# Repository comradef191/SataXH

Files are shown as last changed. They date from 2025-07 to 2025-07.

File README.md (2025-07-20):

# SataXH
This is a simple breakout board that allows you to break-out the 12v & 5v rails of a SATA power connector to JSTXH connectors, allowing for easy integration of non-standard components into a PC such as an ESP-based RGB controller, which requires a 5v source but lacks a PC-compatible power input.

# NOTICE
As of 20JUl25 this board has not yet been tested, however should function.
If you wish to export your own Gerber files, please make sure to have [the Nasin Nanpa font](https://github.com/ETBCOR/nasin-nanpa) installed

## Vendors
- None... yet!

Contact me on Discord if you want to add yourself to this list!

## Bill of Materials
This BoM lists exclusively through-hole components, as SMD components will be assembled for you by JLCPCB/ect

|  Component |QTY | Cost  |  Comment |  Sourcing URL |
|---|----|---|---|---|
|JST-XH 2-Pin | 8  | $0.80 | Power Output | https://www.digikey.co.uk/en/products/detail/jst-sales-america-inc/B2B-XH-A/1651045 |
|1x2 5.08 Screw Terminal | 2  | $2.66 | Power Output | https://www.digikey.co.uk/en/products/detail/phoenix-contact/1729128/260615 |
|SATA 7+15 PCB Connector | 1  | $4.09 | Power Input | https://www.digikey.co.uk/en/products/detail/amphenol-icc-fci/10101788-002CLF/5207025 |

## Gallery



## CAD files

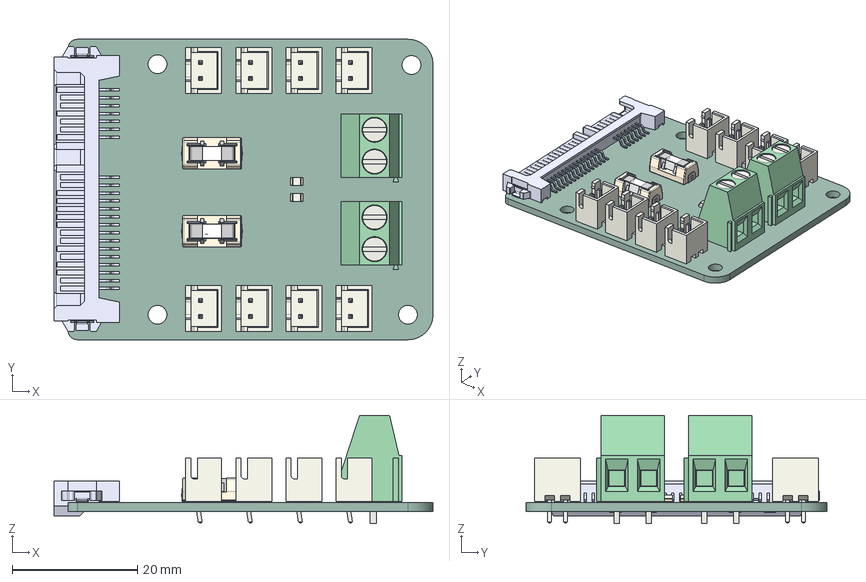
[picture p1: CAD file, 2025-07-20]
SataXH.step
60.5 x 48.0 x 17.3 mm
¼þ1 x 2
¼þ2 x 4
µ艝 x 2
LED_0805_2012Metric x 2
TerminalBlock_Phoenix_MKDS-1,5-2-5.08_1x02_P5.08mm_Horizontal x 2
10101788-002CLF--3DModel-STEP-533217
JST_XH_B2B-XH-A_1x02_P2.50mm_Vertical x 8
SataXH_PCB

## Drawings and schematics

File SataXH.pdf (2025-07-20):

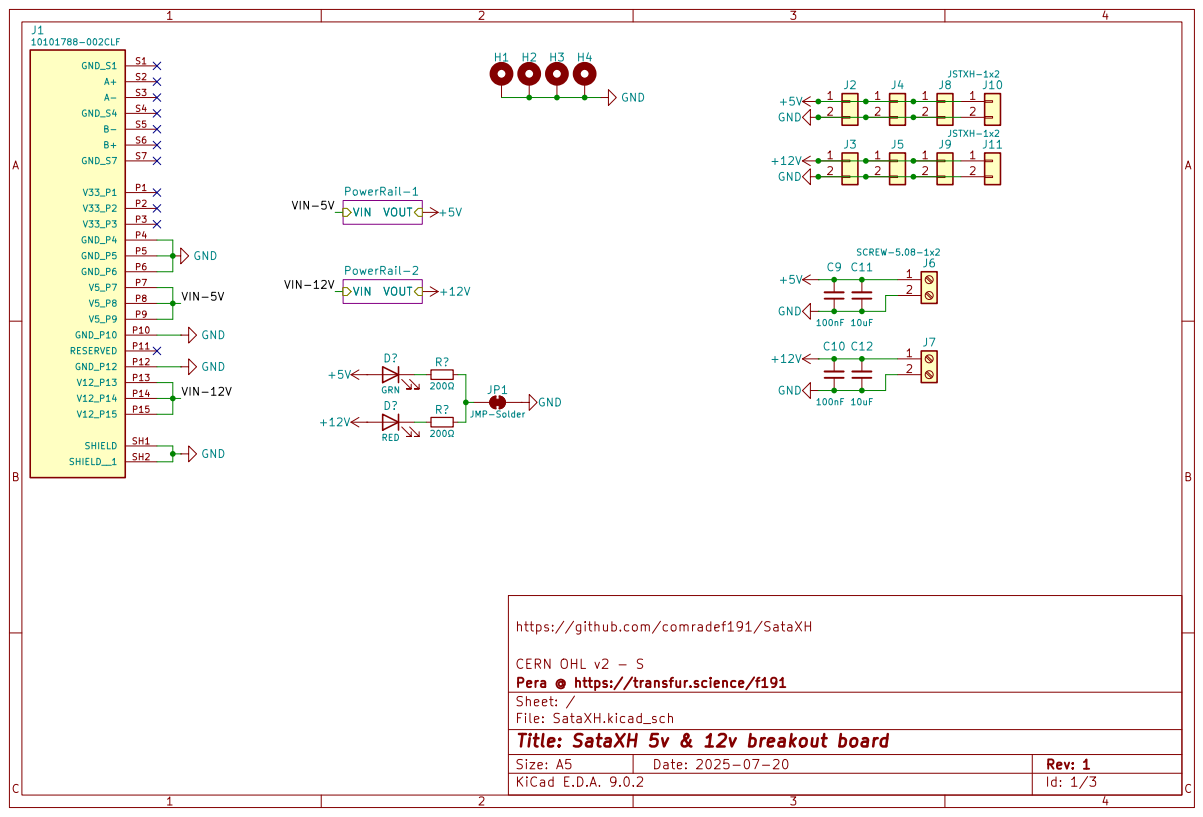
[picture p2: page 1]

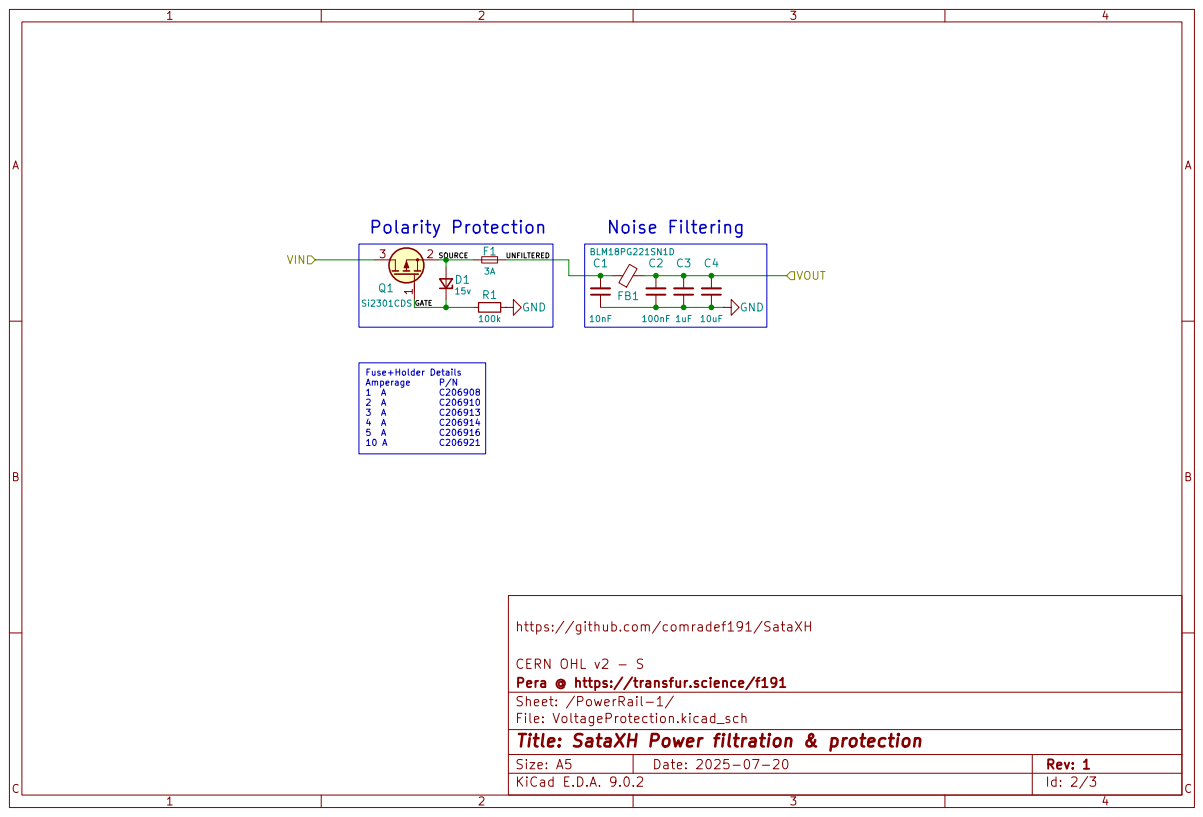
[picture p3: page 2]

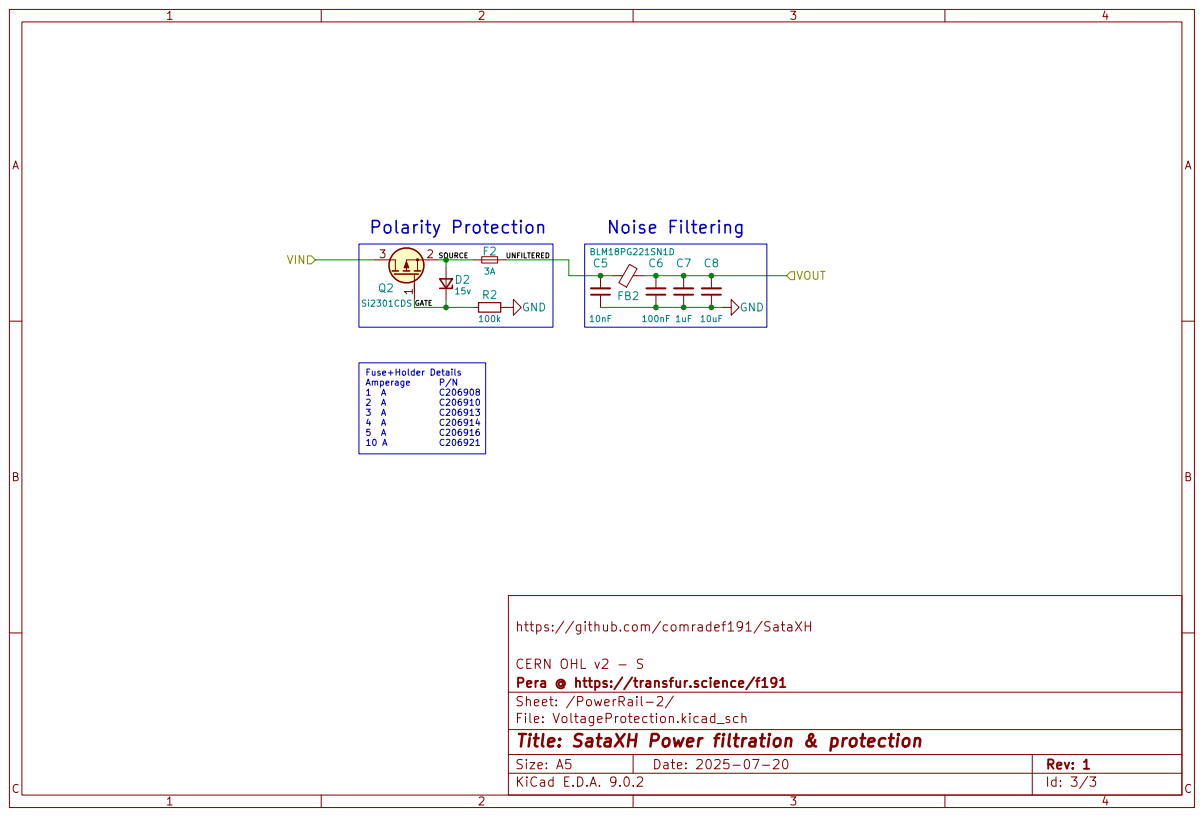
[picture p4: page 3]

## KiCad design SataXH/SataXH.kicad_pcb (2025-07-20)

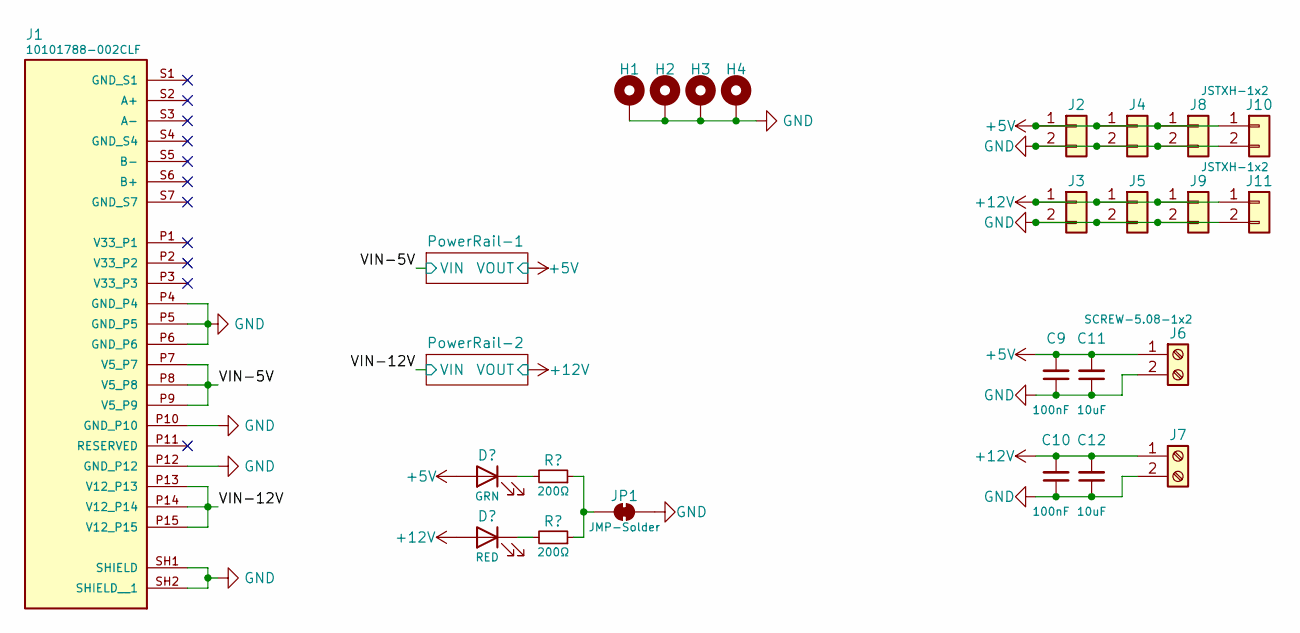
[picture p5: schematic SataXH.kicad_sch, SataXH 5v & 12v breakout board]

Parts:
C9, C10: 100nF; C_0402_1005Metric; LCSC C1525
C11, C12: 10uF; C_0402_1005Metric; LCSC C15525
H1, H2, H3, H4: MountingHole_Pad; M3 Mounting Hole ~ Classic - Pad
J1: 10101788-002CLF; AMPHENOL_10101788-002CLF; LCSC C254657
J2, J3, J4, J5, J8, J9, J10, J11: JSTXH-1x2; JST_XH_B2B-XH-A_1x02_P2.50mm_Vertical; LCSC C5160911
J6, J7: SCREW-5.08-1x2; TerminalBlock_Phoenix_MKDS-1,5-2-5.08_1x02_P5.08mm_Horizont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; LCSC C5188485
JP1: JMP-Solder; SolderJumper-2_P1.3mm_Bridged_Pad1.0x1.5mm

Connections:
+5V: C9.2, C11.2, J2.1, J4.1, J6.1, J8.1, J10.1; also elsewhere on the board
+12V: C10.2, C12.2, J3.1, J5.1, J7.1, J9.1, J11.1; also elsewhere on the board
/VIN-5V: J1.P7 (V5_P7), J1.P8 (V5_P8), J1.P9 (V5_P9); also elsewhere on the board
/VIN-12V: J1.P13 (V12_P13), J1.P14 (V12_P14), J1.P15 (V12_P15); also elsewhere on the board
GND: C9.1, C10.1, C11.1, C12.1, H1.1, H2.1, H3.1, H4.1, J1.P4 (GND_P4), J1.P5 (GND_P5), J1.P6 (GND_P6), J1.P10 (GND_P10), J1.P12 (GND_P12), J1.SH1 (SHIELD), J1.SH2 (SHIELD__1), J2.2, J3.2, J4.2, J5.2, J6.2, J7.2, J8.2, J9.2, J10.2, J11.2, JP1.2 (B); also elsewhere on the board
unnamed 13: JP1.1 (A); also elsewhere on the board

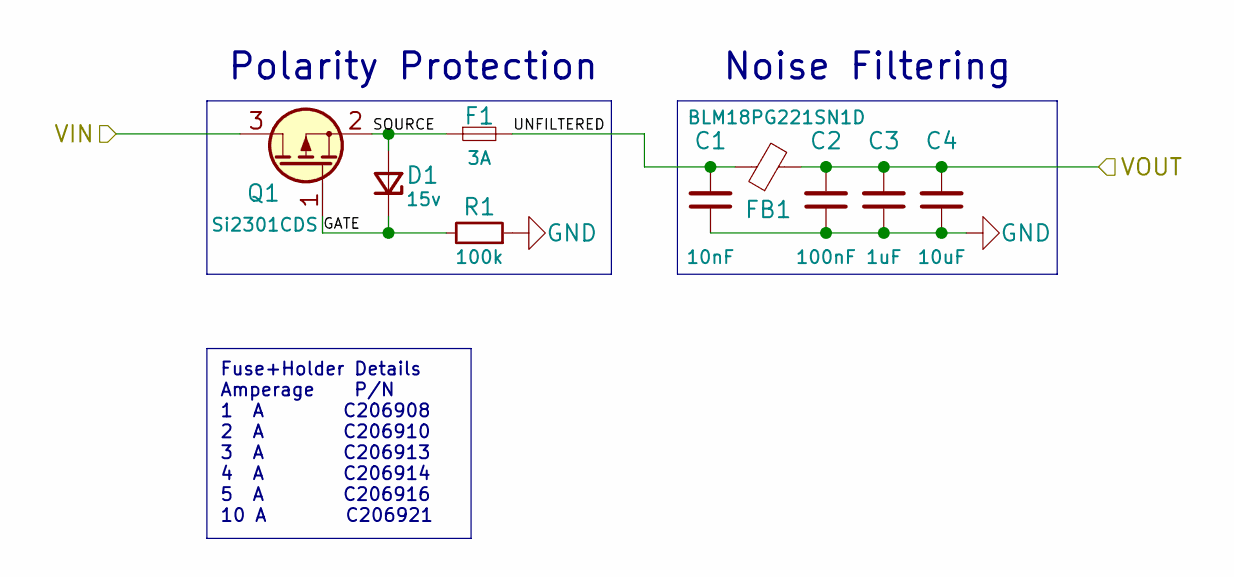
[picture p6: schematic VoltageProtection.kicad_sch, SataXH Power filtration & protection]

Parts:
C1: 10nF; C_0402_1005Metric; LCSC C15195
C2: 100nF; C_0402_1005Metric; LCSC C1525
C3: 1uF; C_0402_1005Metric; LCSC C52923
C4: 10uF; C_0402_1005Metric; LCSC C15525
D1: 15v; D_SOD-123; LCSC C177014
F1: 3A; Fuseholder_Littelfuse_Nano2_154x; LCSC C206913
FB1: BLM18PG221SN1D; L_0603_1608Metric; LCSC C80165
Q1: Si2301CDS; SOT-23; LCSC C10487
R1: 100k; R_0402_1005Metric; LCSC C25741

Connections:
+5V: C2.2, C3.2, C4.2, FB1.2; also elsewhere on the board
/PowerRail-1/GATE: D1.1 (K), Q1.1 (G), R1.2
/PowerRail-1/SOURCE: D1.2 (A), F1.1, Q1.2 (S)
/PowerRail-1/UNFILTERED: C1.2, F1.2, FB1.1
/VIN-5V: Q1.3 (D); also elsewhere on the board
GND: C1.1, C2.1, C3.1, C4.1, R1.1; also elsewhere on the board

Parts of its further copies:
C5: 10nF; C_0402_1005Metric; LCSC C15195
C6: 100nF; C_0402_1005Metric; LCSC C1525
C7: 1uF; C_0402_1005Metric; LCSC C52923
C8: 10uF; C_0402_1005Metric; LCSC C15525
D2: 15v; D_SOD-123; LCSC C177014
F2: 3A; Fuseholder_Littelfuse_Nano2_154x; LCSC C206913
FB2: BLM18PG221SN1D; L_0603_1608Metric; LCSC C80165
Q2: Si2301CDS; SOT-23; LCSC C10487
R2: 100k; R_0402_1005Metric; LCSC C25741

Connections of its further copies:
+12V: C6.2, C7.2, C8.2, FB2.2; also elsewhere on the board
/PowerRail-2/GATE: D2.1 (K), Q2.1 (G), R2.2
/PowerRail-2/SOURCE: D2.2 (A), F2.1, Q2.2 (S)
/PowerRail-2/UNFILTERED: C5.2, F2.2, FB2.1
/VIN-12V: Q2.3 (D); also elsewhere on the board
GND: C5.1, C6.1, C7.1, C8.1, R2.1; also elsewhere on the board

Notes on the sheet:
Noise Filtering
Polarity Protection
Fuse+Holder Details Amperage P/N 1 A C206908 2 A C206910 3 A C206913 4 A C206914 5 A C206916 10 A C206921

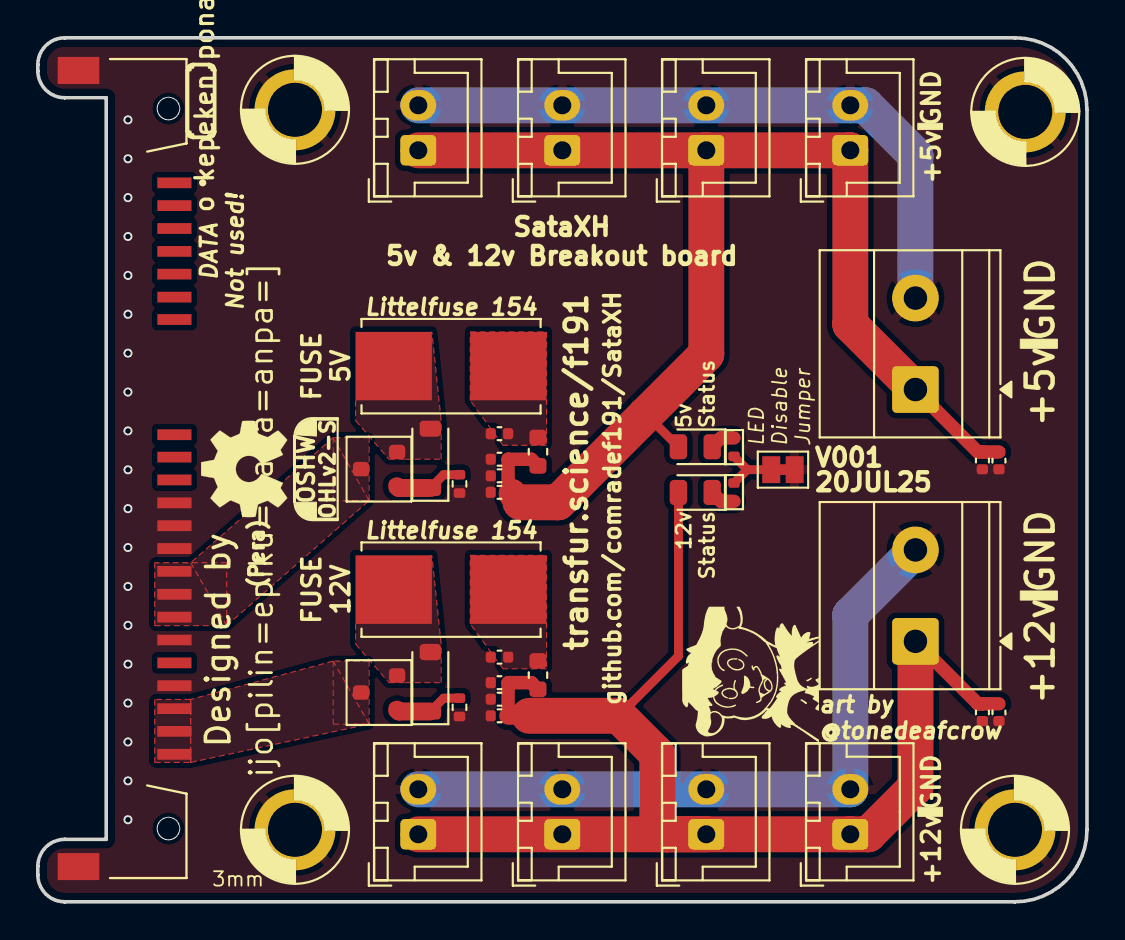
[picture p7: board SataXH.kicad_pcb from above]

Board: 2 copper layers, 58.3 x 48.0 mm, 42 parts (0 on the bottom side), 14 nets.

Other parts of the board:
D3: GRN; LED_0805_2012Metric
D4: RED; LED_0805_2012Metric
R3, R4: 200Ω; R_0402_1005Metric

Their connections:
+5V: D3.2 (A); also elsewhere on the board
+12V: D4.2 (A); also elsewhere on the board
unnamed: D3.1 (K), R3.2
unnamed: D4.1 (K), R4.2
unnamed 13: R3.1, R4.1; also elsewhere on the board

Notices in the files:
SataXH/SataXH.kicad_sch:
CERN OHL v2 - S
